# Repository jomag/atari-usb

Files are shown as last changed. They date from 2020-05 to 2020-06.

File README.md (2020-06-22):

Atari USB
=========

This repo contains the PCB and firmware of an Atari joystick to USB
adapter, allowing old, golden joysticks such as TAC-2 to be used with
modern computers, or products such as "The C64" that use USB for
joysticks.

**"The C64" is picky about joysticks, and this firmware has not yet
been confirmed to be compatible with it. This will be updated.**

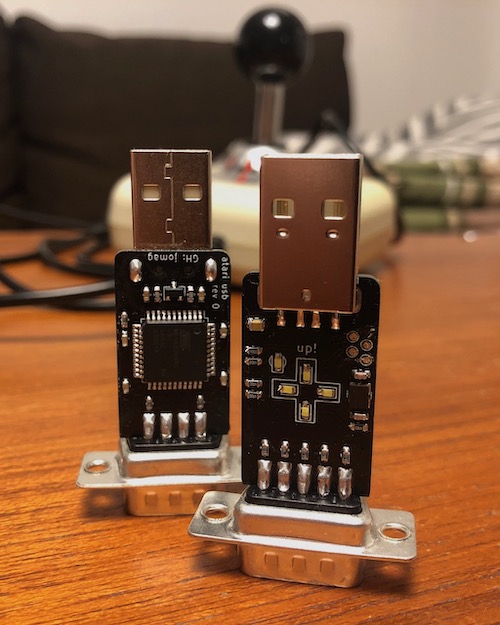
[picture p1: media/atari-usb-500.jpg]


Architecture
------------

The adapter is primarily built around an ATmega32u4 with an Arduino
bootloader. This allows the firmware to be tweaked and flashed using
the standard Arduino IDE. Board type: "Adafruit Feather 32u4".

PCB revisions
-------------

### Rev 0

Current revision.

Everything works, but the initial bootloader transfer is a bit
complicated as it requires temporary soldering an ISP header to
a few pads on the board. This will be revisited for rev 1.

Firmware
--------

Current firmware is very simplistic, but it works well. The joystick
HID code was copied from Matthew Heironimus.

License
-------

The current release contains code from Matthew Heironimus under
the LGPL license, so the entire project is LGPL for now.

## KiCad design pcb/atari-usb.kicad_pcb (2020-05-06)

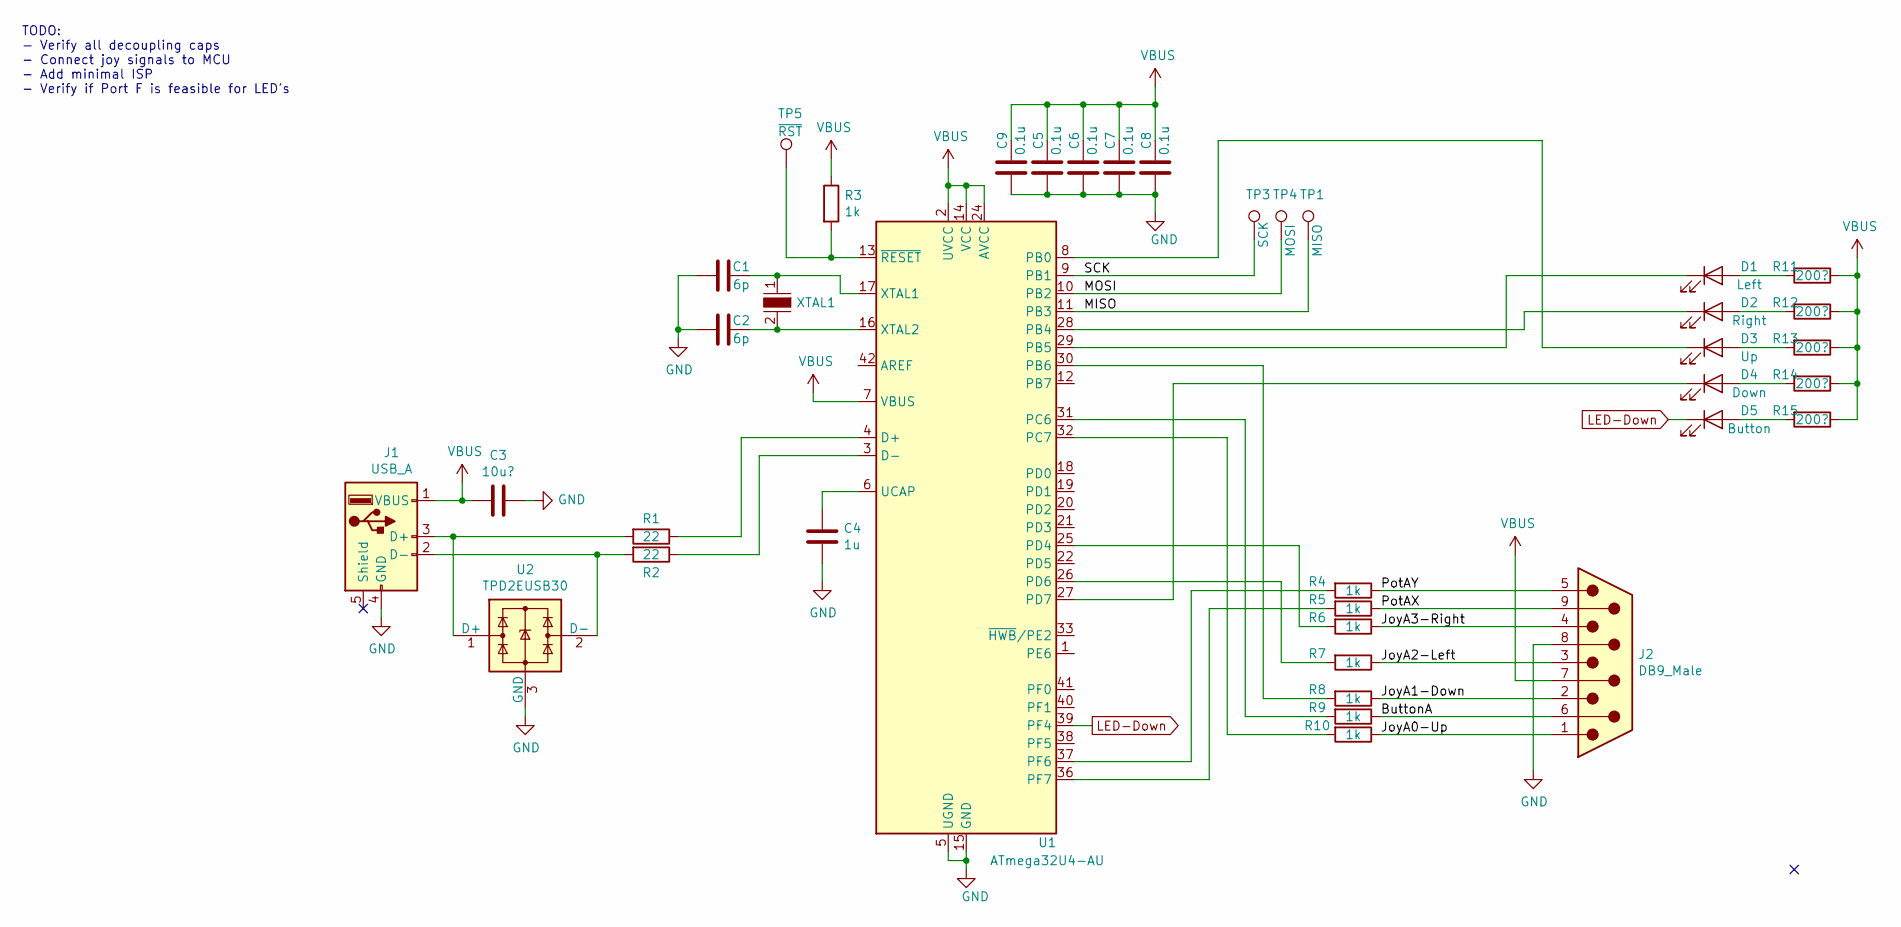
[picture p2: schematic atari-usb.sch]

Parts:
C1, C2: 6p; C_0603_1608Metric
C3: 10u?; C_0805_2012Metric
C4: 1u; C_0603_1608Metric
C5, C6, C7, C8, C9: 0.1u; C_0603_1608Metric
D1: Left; LED_0603_1608Metric
D2: Right; LED_0603_1608Metric
D3: Up; LED_0603_1608Metric
D4: Down; LED_0603_1608Metric
D5: Button; LED_0603_1608Metric
J1: USB_A; USB_A_CNCTech_1001-011-01101_Horizontal
J2: DB9_Male; db9-edge-hack
R1, R2: 22; R_0603_1608Metric
R3, R4, R5, R6, R7, R8, R9, R10: 1k; R_0603_1608Metric
R11, R12, R13, R14, R15: 200?; R_0603_1608Metric
TP1: MISO; TestPoint_Pad_D1.0mm
TP3: SCK; TestPoint_Pad_D1.0mm
TP4: MOSI; TestPoint_Pad_D1.0mm
TP5: ~RST; TestPoint_Pad_D1.0mm
U1: ATmega32U4-AU; TQFP-44_10x10mm_P0.8mm
U2: TPD2EUSB30; SOT-23
XTAL1: NX3225GD-8MHZ-STD-CRA-3; SMD-2_3.2x2.5mm; MPN NX3225GD-8MHZ-STD-CRA-3; Digi-Key_PN 644-1178-1-ND

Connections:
/ButtonA: J2.6, R9.1
/JoyA0-Up: J2.1, R10.1
/JoyA1-Down: J2.2, R8.1
/JoyA2-Left: J2.3, R7.1
/JoyA3-Right: J2.4, R6.1
/PotAX: J2.9, R5.1
/PotAY: J2.5, R4.1
GND: C1.2, C2.2, C3.1, C4.1, C5.1, C6.1, C7.1, C8.1, C9.1, J1.4 (GND), J2.8, U1.5 (UGND), U1.15 (GND), U1.23 (GND), U1.35 (GND), U1.43 (GND), U2.3 (GND)
LED-Down: D5.1 (K), U1.39 (PF4)
unnamed: C1.1, U1.17 (XTAL1), XTAL1.1
unnamed: C2.1, U1.16 (XTAL2), XTAL1.2
unnamed: C4.2, U1.6 (UCAP)
unnamed: D1.1 (K), U1.29 (PB5)
unnamed: D1.2 (A), R11.2
unnamed: D2.1 (K), U1.28 (PB4)
unnamed: D2.2 (A), R12.2
unnamed: D3.1 (K), U1.8 (PB0)
unnamed: D3.2 (A), R13.2
unnamed: D4.1 (K), U1.27 (PD7)
unnamed: D4.2 (A), R14.2
unnamed: D5.2 (A), R15.2
unnamed: J1.2 (D-), R2.2, U2.2 (D-)
unnamed: J1.3 (D+), R1.2, U2.1 (D+)
unnamed: R1.1, U1.4 (D+)
unnamed: R2.1, U1.3 (D-)
unnamed: R3.2, TP5.1, U1.13 (~RESET)
unnamed: R4.2, U1.37 (PF6)
unnamed: R5.2, U1.36 (PF7)
unnamed: R6.2, U1.25 (PD4)
unnamed: R7.2, U1.26 (PD6)
unnamed: R8.2, U1.30 (PB6)
unnamed: R9.2, U1.31 (PC6)
unnamed: R10.2, U1.32 (PC7)
unnamed: TP1.1, U1.11 (PB3)
unnamed: TP3.1, U1.9 (PB1)
unnamed: TP4.1, U1.10 (PB2)
VBUS: C3.2, C5.2, C6.2, C7.2, C8.2, C9.2, J1.1 (VBUS), J2.7, R3.1, R11.1, R12.1, R13.1, R14.1, R15.1, U1.2 (UVCC), U1.7 (VBUS), U1.14 (VCC), U1.24 (AVCC), U1.34 (VCC), U1.44 (AVCC)

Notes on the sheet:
TODO: - Verify all decoupling caps - Connect joy signals to MCU - Add minimal ISP - Verify if Port F is feasible for LED's

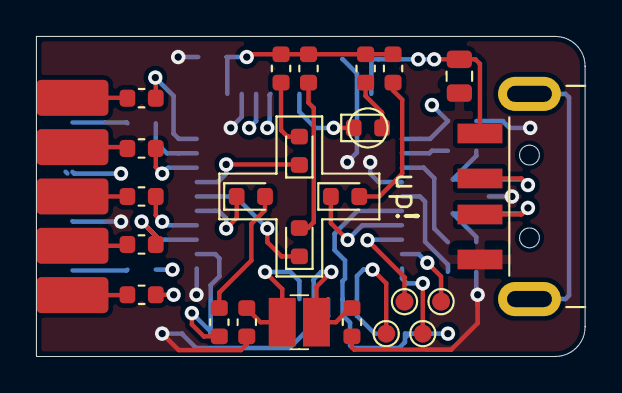
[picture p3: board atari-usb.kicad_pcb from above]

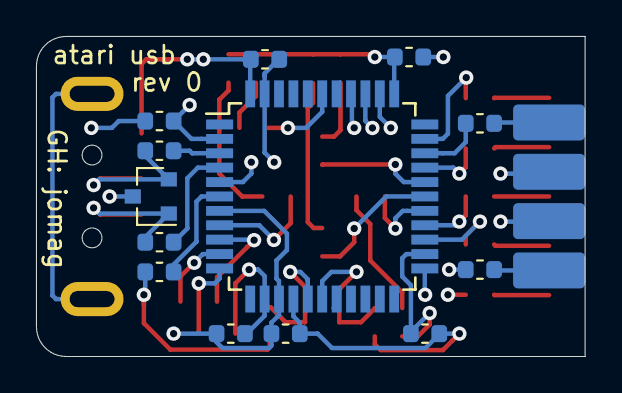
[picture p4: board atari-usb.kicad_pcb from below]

Board: 4 copper layers, 30.5 x 17.8 mm, 38 parts (13 on the bottom side), 37 nets.

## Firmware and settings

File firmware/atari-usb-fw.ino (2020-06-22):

// Joystick pins:
//
// - Left: PD4 (pin 25)
// - Right: PD6 (pin 26, arduino 12)
// - Up: PC7 (pin 32, arduino 13)
// - Down: PB6 (pin 30, arduino 10)
// - Button: PC6 (pin 31, arduino 5)
//
// LED pins:
// - Left: PB5 (pin 29)
// - Right: PB4 (pin 28, arduino 9)
// - Up: PB0 (pin 8)
// - Down: PD7 (pin 27, arduino 6)
// - Button: PF4 (pin 39, arduino 21)

#include "Joystick.h"

typedef enum {
  JOY_UP = 0,
  JOY_DOWN,
  JOY_LEFT,
  JOY_RIGHT,
  JOY_BUTTON
} InputType;

InputType input_types[5] = {
  JOY_UP,
  JOY_DOWN,
  JOY_LEFT,
  JOY_RIGHT,
  JOY_BUTTON
};

bool joy_read(InputType type)
{
  switch (type) {
  case JOY_UP: return !(PINC & (1 << 7));
  case JOY_DOWN: return !(PINB & (1 << 6));
  case JOY_LEFT: return !(PIND & (1 << 6));
  case JOY_RIGHT: return !(PIND & (1 << 4));
  case JOY_BUTTON: return !(PINC & (1 << 6));
  default: return false;
  }
}

void led_set(InputType type, bool on)
{
  if (on) {
    switch (type) {
    case JOY_UP: PORTB &= ~(1 << 0); return;
    case JOY_DOWN: PORTD &= ~(1 << 7); return;
    case JOY_LEFT: PORTB &= ~(1 << 5); return;
    case JOY_RIGHT: PORTB &= ~(1 << 4); return;
    case JOY_BUTTON: PORTF &= ~(1 << 4); return;
    }
  } else {
    switch (type) {
    case JOY_UP: PORTB |= 1 << 0; return;
    case JOY_DOWN: PORTD |= 1 << 7; return;
    case JOY_LEFT: PORTB |= 1 << 5; return;
    case JOY_RIGHT: PORTB |= 1 << 4; return;
    case JOY_BUTTON: PORTF |= 1 << 4; return;
    }
  }
}

void setup() {
  // Port B: PB6 joystick, PB0+PB4+PB5 led
  DDRB = (1 << 0) | (1 << 4) | (1 << 5);
  PORTB = (1 << 6);

  // Port C: PC6+PC7 joystick
  DDRC = 0;
  PORTC = (1 << 6) | (1 << 7);
  
  // Port D: PD4+PD6 joystick, PD7 led
  DDRD = (1 << 7);
  PORTD = (1 << 4) | (1 << 6);

  // Port F: PF4 led
  DDRF = (1 << 4);
  PORTF = 0;

  Joystick.begin();
}

void loop() {
  bool left, right, up, down, button;
  uint8_t x;
  uint8_t y;

  left = joy_read(JOY_LEFT);
  right = joy_read(JOY_RIGHT);
  up = joy_read(JOY_UP);
  down = joy_read(JOY_DOWN);
  button = joy_read(JOY_BUTTON);

  led_set(JOY_UP, up);
  led_set(JOY_DOWN, down);
  led_set(JOY_LEFT, left);
  led_set(JOY_RIGHT, right);
  led_set(JOY_BUTTON, button);
  
  if (up && !down) {
    Joystick.setYAxis(-127);
  } else if (down && !up) {
    Joystick.setYAxis(127);
  } else {
    Joystick.setYAxis(0);
  }

  if (left && !right) {
    Joystick.setXAxis(-127);
  } else if (right && !left) {
    Joystick.setXAxis(127);
  } else {
    Joystick.setXAxis(0);
  }

  Joystick.setButton(0, button);
}

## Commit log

2020-04-26 Much of the schema and layout done
    [atari-usb.kicad_pcb, atari-usb.sch]
2020-05-06 Revision 0 done
    [atari-usb.kicad_pcb, atari-usb.sch]
2020-06-22 Gerbers for rev 0
    [atari-usb-B_Cu.gbr, atari-usb-B_Mask.gbr, atari-usb-B_Paste.gbr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]
2020-06-22 Minor fixes during assembly
    [atari-usb.sch]
2020-06-22 Move PCB to subdirectory
    [atari-usb-B_Cu.gbr, atari-usb-B_Mask.gbr, atari-usb-B_Paste.gbr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]
